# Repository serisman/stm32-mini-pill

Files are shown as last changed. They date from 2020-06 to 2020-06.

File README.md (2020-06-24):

# stm32-mini-pill
This is a development board for (LQFP-48) STM32 microcontrollers like the STM32F103C8T6 and STM32F072C8T6.
It is effectively 1/2 of the infamous 'blue-pill'.

Hold down the BOOT0/PA15 button while powering on (or press RESET and BOOT0 together, then release RESET) to access the built-in USB DFU bootloader.  The BOOT0/PA15 button can also be used for user input while not in the bootloader.

PCB design was done using KiCad.

PCBs are available at OSHPARK (or upload the included gerber.zip to your favorite board house):
https://oshpark.com/shared_projects/8USgL5pT

## 3D Renders:
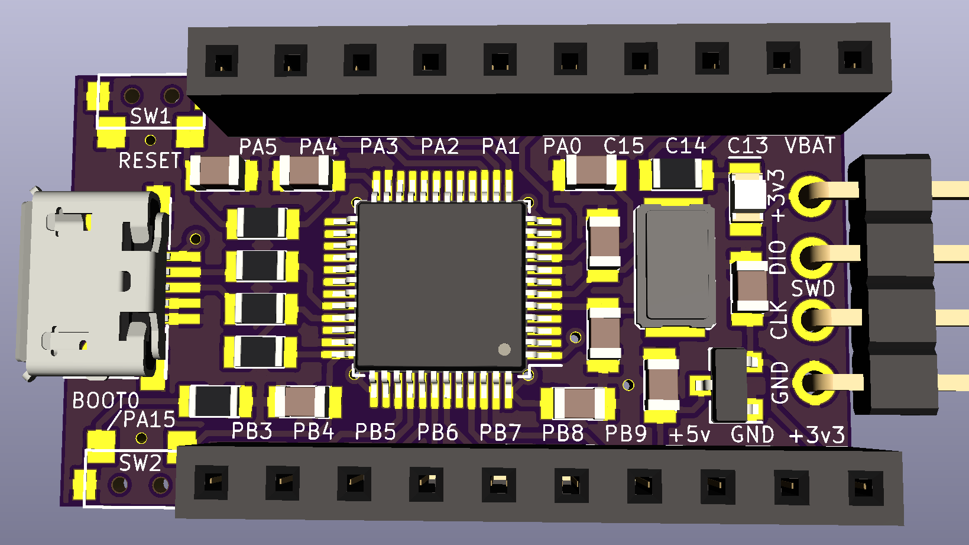
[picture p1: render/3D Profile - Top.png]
3D Profile - Top

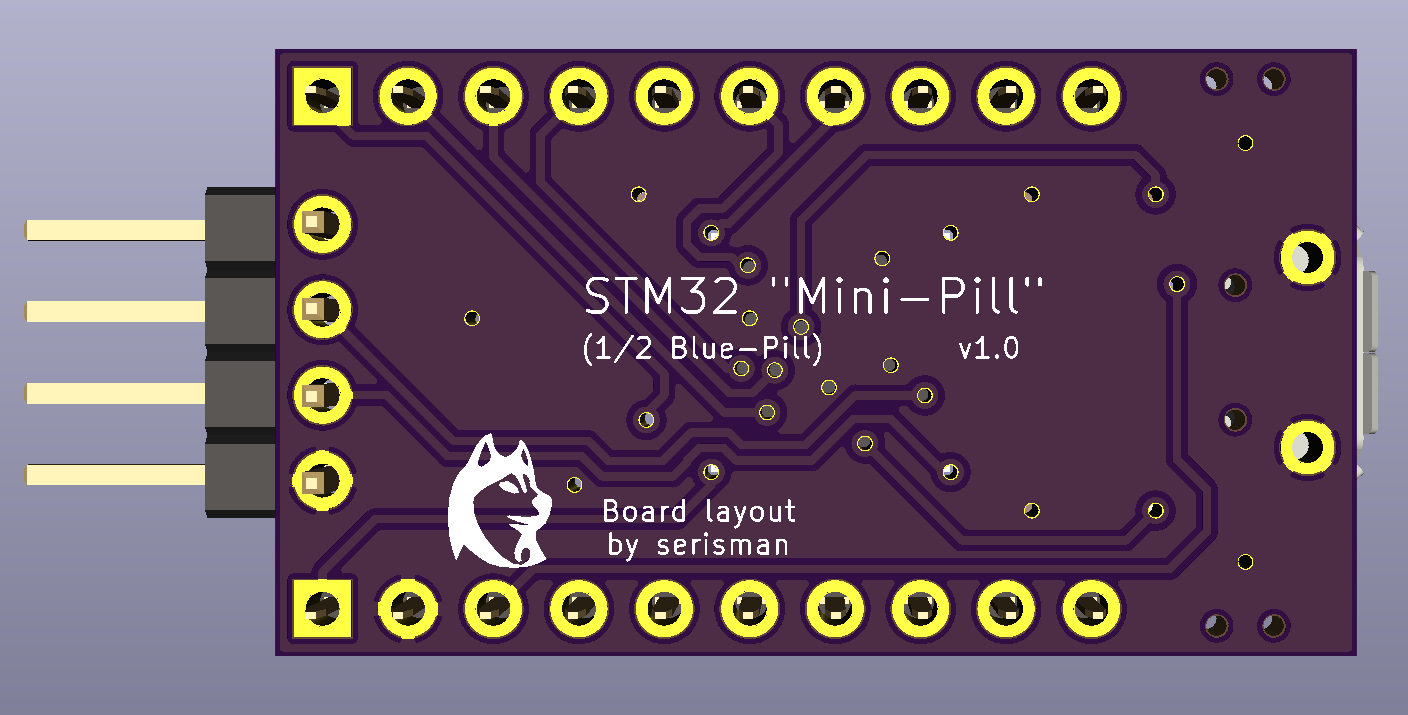
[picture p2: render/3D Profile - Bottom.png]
3D Profile - Bottom


## Finished Product:
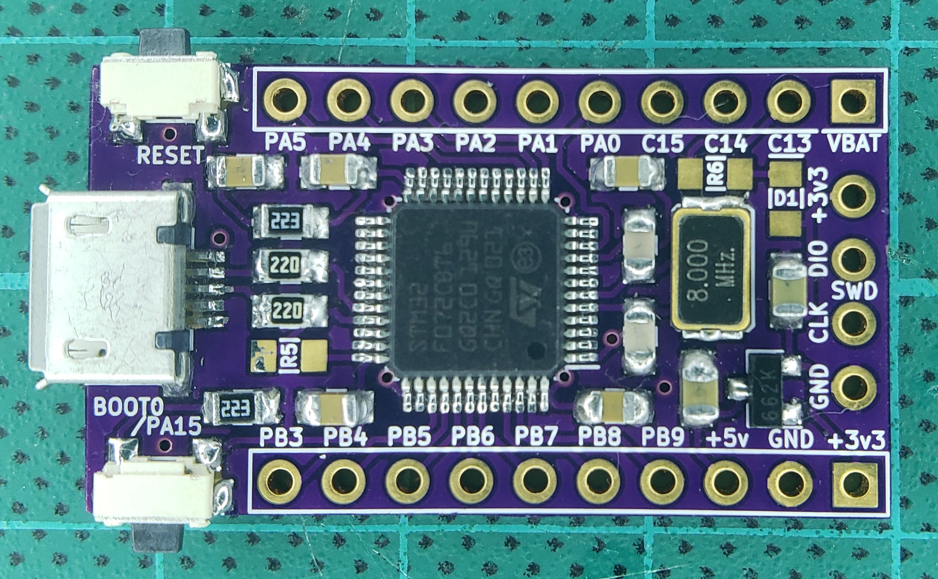
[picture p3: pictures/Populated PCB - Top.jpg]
Populated - Top

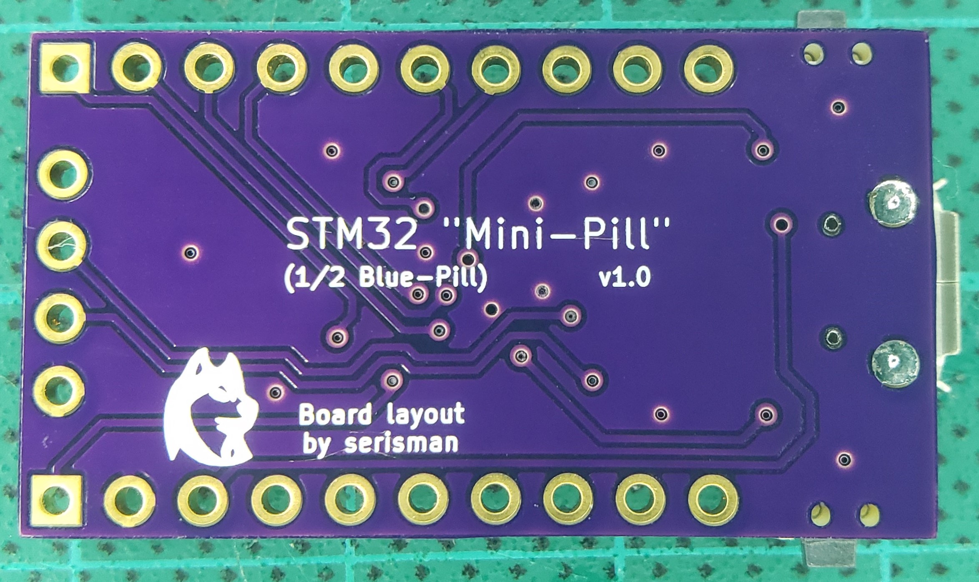
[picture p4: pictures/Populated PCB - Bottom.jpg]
Populated - Bottom


## Schematic:
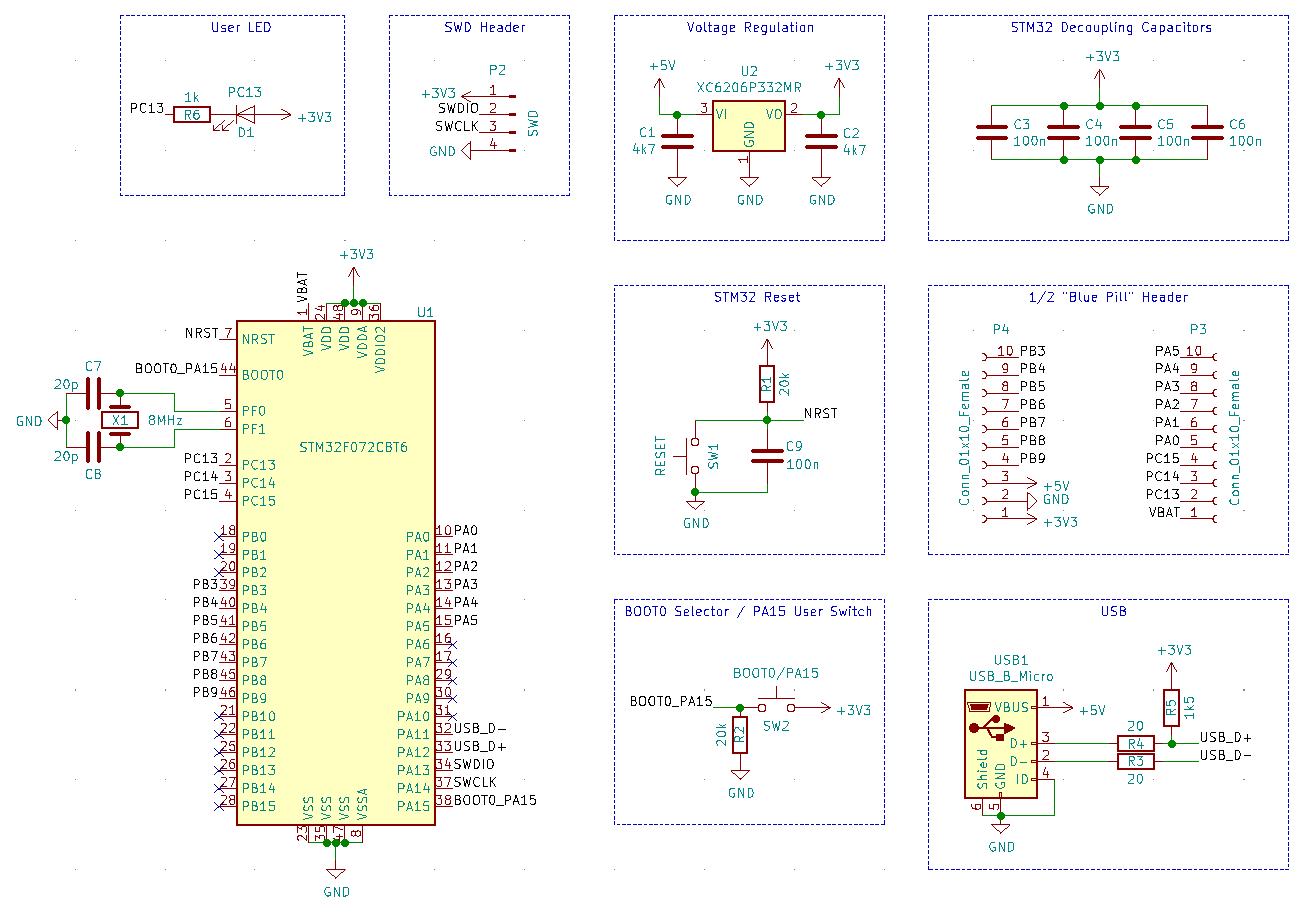
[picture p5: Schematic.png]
Schematic


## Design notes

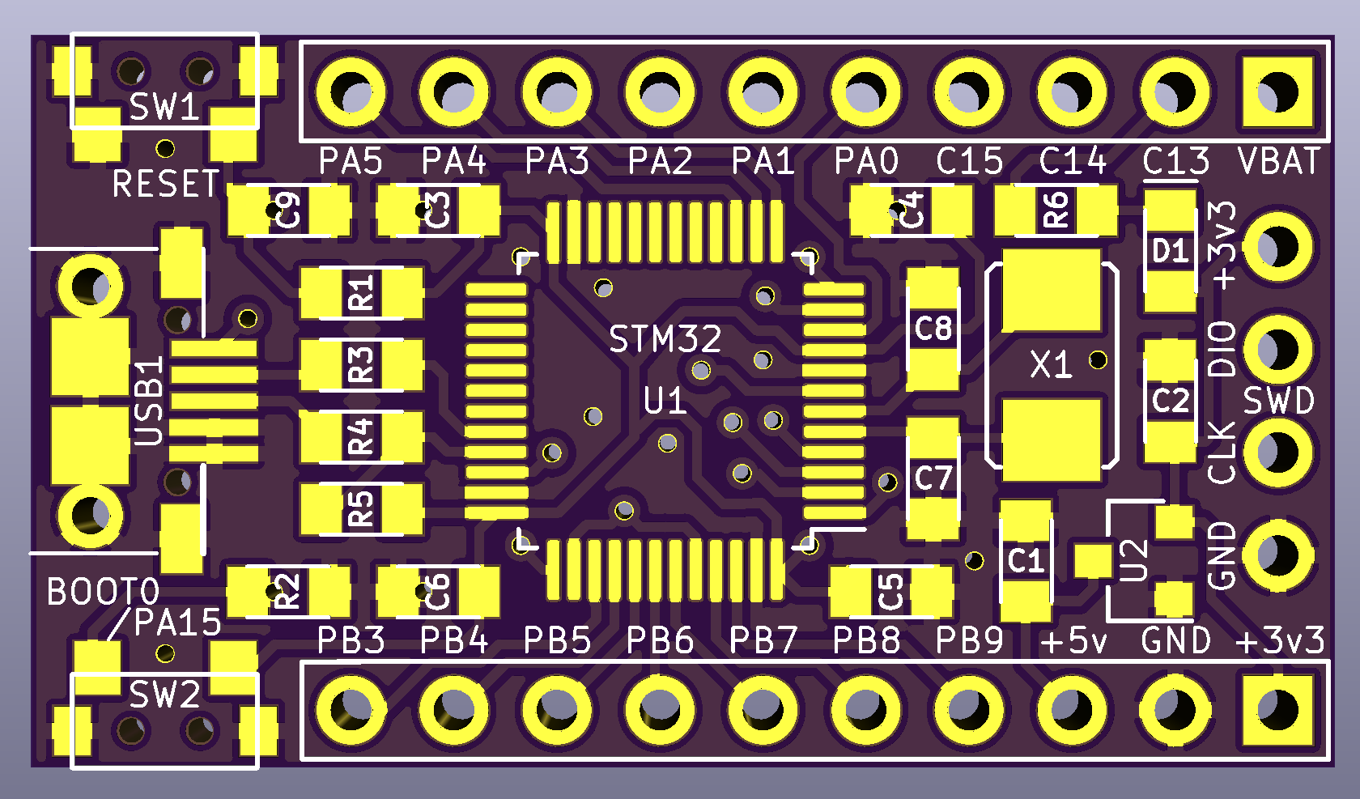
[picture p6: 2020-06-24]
render/PCB - Top.png

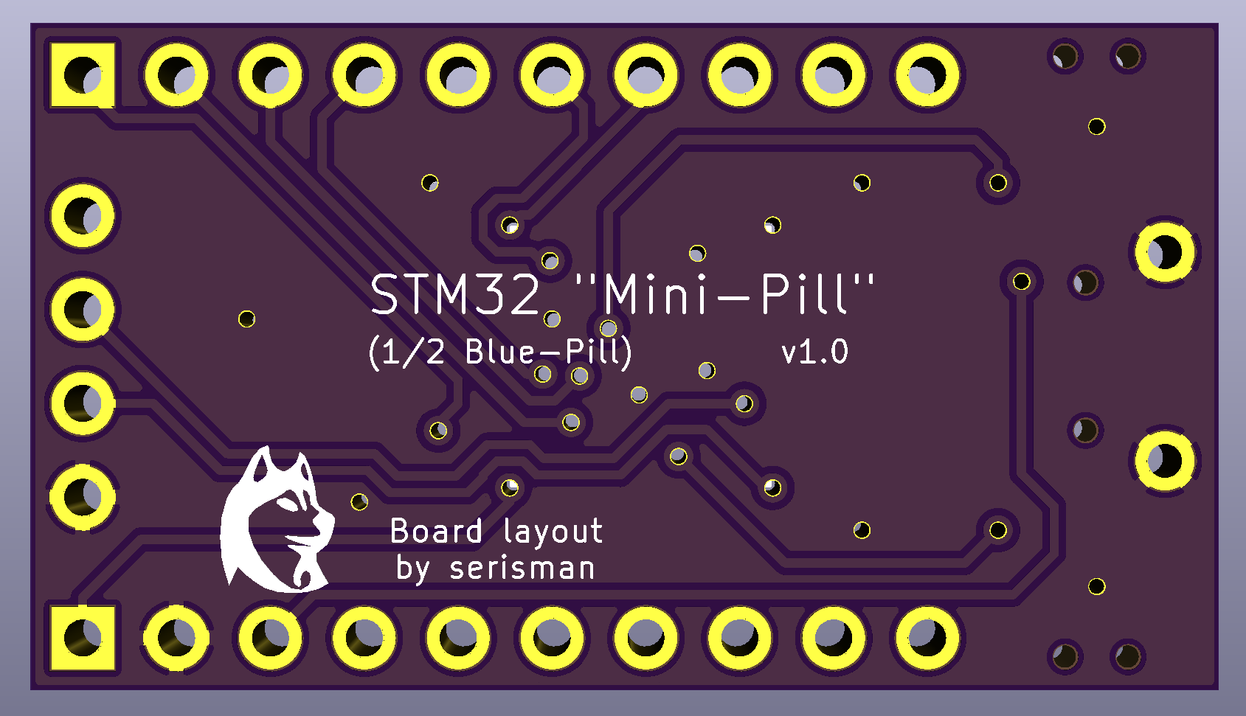
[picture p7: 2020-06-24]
render/PCB - Bottom.png

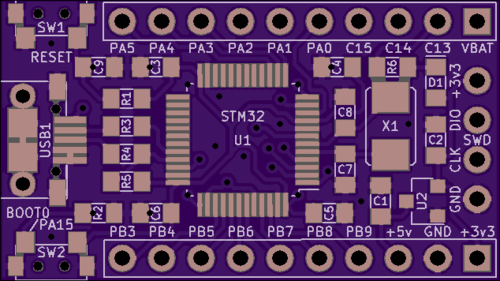
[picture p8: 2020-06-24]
render/OSHPARK - Top.png

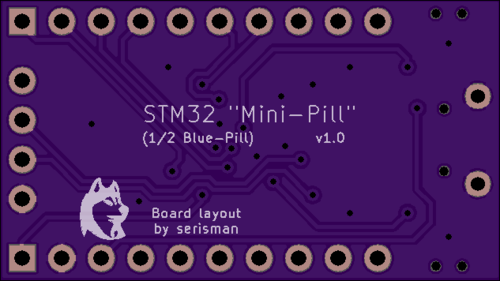
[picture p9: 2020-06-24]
render/OSHPARK - Bottom.png

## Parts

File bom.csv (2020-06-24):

References | Qty | Package | Description | MPN | LCSC | Comments
U1 | 1 | LQFP-48 |  | STM32F103C8T6 | C8734 | STM32 MCU - Can also be any other pin compatible (LQFP-48) STM32 MCU (i.e. STM32F072C8T6)
U2 | 1 | SOT-23 |  | XC6206P332MR | C347376 | 3.3v LDO regulator
X1 | 1 | 5032 2-pin |  | X50328MSB2GI | C115962 | 8MHz Crystal
USB1 | 1 | micro USB |  | MICRO5.9mmusb | C393940 | micro USB connector
SW1,SW2 | 2 | 3.5x4.55 mm |  | TS24CA | C393942 | RESET and BOOT0/PA15 buttons - side mount
C1,C2 | 2 | 0805 | 4.7uF 0805 Y5V | 0805F475Z100CT | C123638 | 3.3v LDO regulator in/out capacitors
C3,C4,C5,C6,C9 | 5 | 0805 | 100nF 0805 Y5V | 0805F104M500NT | C28378 | Bypass capacitors, Reset capacitor
C7,C8 | 2 | 0805 | 20pF 0805 C0G | 0805CG200J500NT | C94472 | Crystal load capacitors
R1,R2 | 2 | 0805 | 20k 0805 | 0805W8J0203T5E | C25624 | Button Pull-up/down resistors
R3,R4 | 2 | 0805 | 20 0805 | 0805W8J0200T5E | C25293 | USB resistors
R5 | 1 | 0805 | 1.5k 0805 | 0805W8J0152T5E | C26015 | USB pull-up (optional for some MCUs)
R6 | 1 | 0805 | 1k 0805 | 0805W8F1001T5E | C17513 | User LED current limit
D1 | 1 | 0805 |  | ORH-B35A | C205441 | User LED
P2 | 1 | 1x4 pin header |  | C91552 | C91552 | SWD header - right angle
P3,P4 | 2 | 1x10 pin header |  | C57369 | C57369 | User headers

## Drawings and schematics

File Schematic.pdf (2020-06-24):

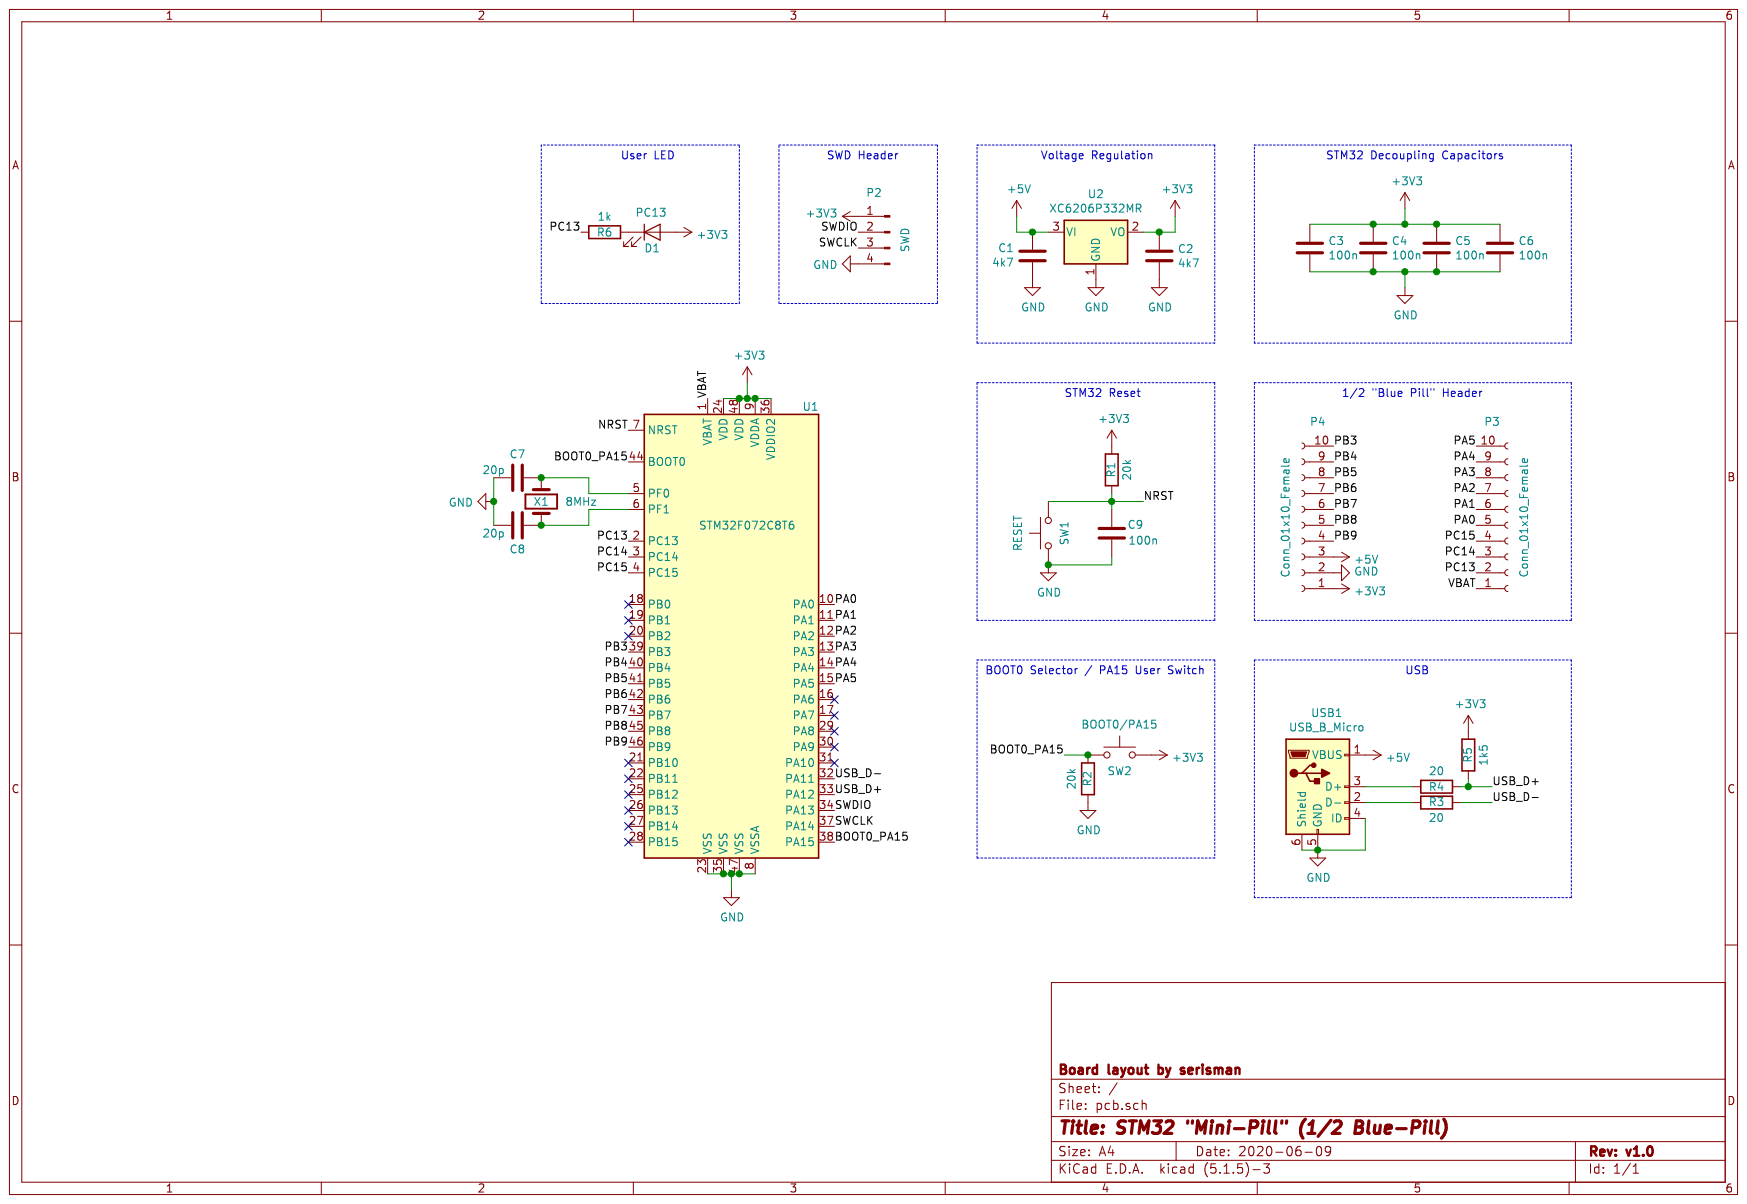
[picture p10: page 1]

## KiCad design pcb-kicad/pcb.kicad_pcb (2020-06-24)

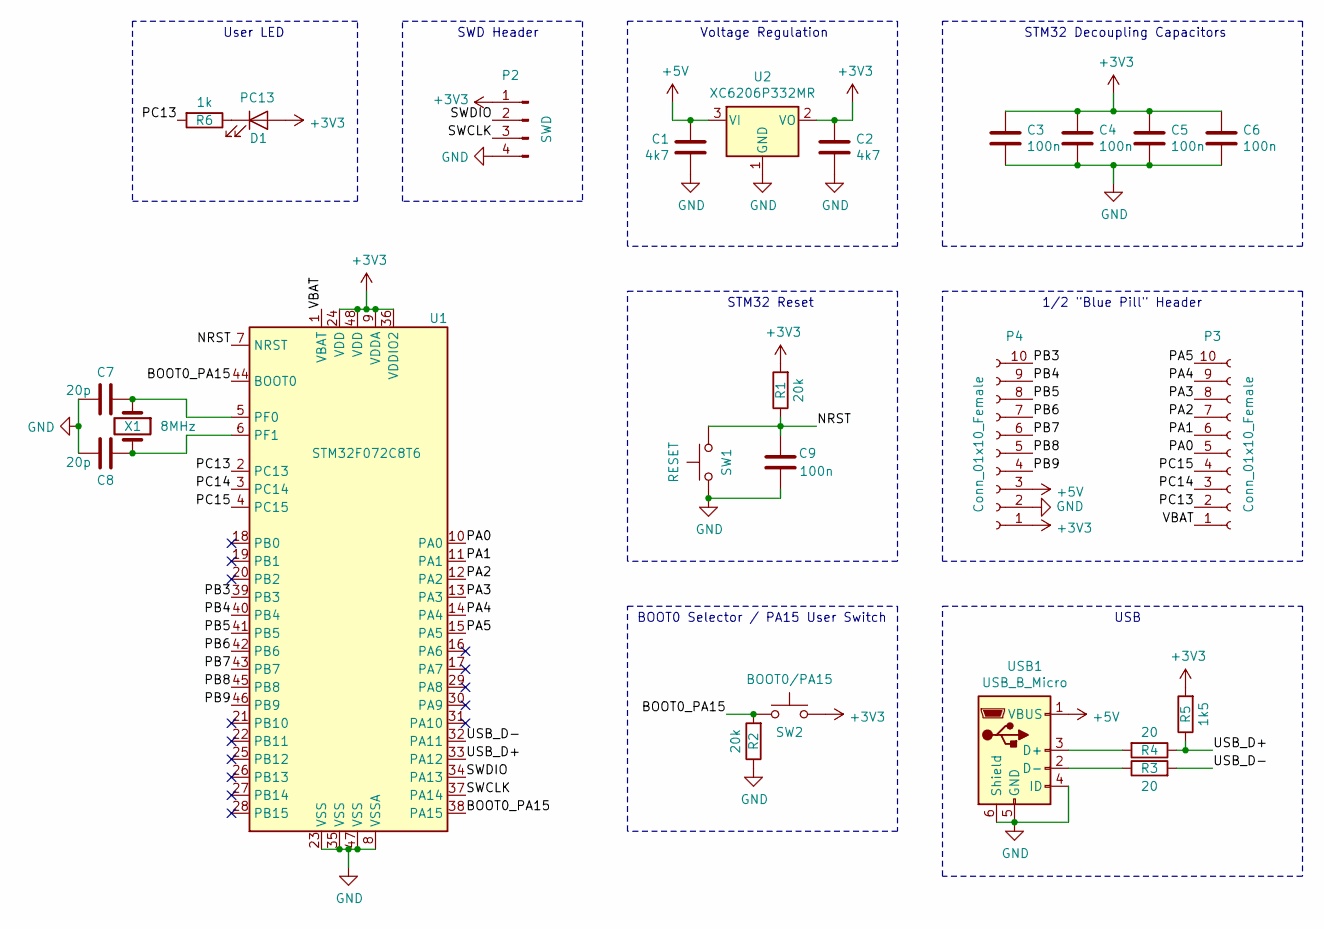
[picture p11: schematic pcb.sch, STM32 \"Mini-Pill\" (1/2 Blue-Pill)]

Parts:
C1, C2: 4k7; C_0805
C3, C4, C5, C6, C9: 100n; C_0805
C7, C8: 20p; C_0805
D1: PC13; LED_0805
P2: SWD; PinHeader_1x04_P2.54mm_Horizontal
P3, P4: Conn_01x10_Female; PinSocket_1x10_P2.54mm_Vertical
R1, R2: 20k; R_0805
R3, R4: 20; R_0805
R5: 1k5; R_0805
R6: 1k; R_0805
SW1: RESET; SMD-SW_Push_3.5x4.55_Side
SW2: BOOT0/PA15; SMD-SW_Push_3.5x4.55_Side
U1: STM32F072C8T6; LQFP-48_7x7mm_P0.5mm
U2: XC6206P332MR; SOT-23
USB1: USB_B_Micro; USB_Micro_B_Male
X1: 8MHz; Crystal_SMD_5032-2Pin_5.0x3.2mm

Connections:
+3V3: C2.1, C3.1, C4.1, C5.1, C6.1, D1.2 (A), P2.1, P4.1, R1.2, R5.2, SW2.1, U1.9 (VDDA), U1.24 (VDD), U1.36 (VDDIO2), U1.48 (VDD), U2.2 (VO)
+5V: C1.2, P4.3, U2.3 (VI), USB1.1 (VBUS)
/BOOT0_PA15: R2.2, SW2.2, U1.38 (PA15), U1.44 (BOOT0)
/NRST: C9.2, R1.1, SW1.2, U1.7 (NRST)
/PA0: P3.5, U1.10 (PA0)
/PA1: P3.6, U1.11 (PA1)
/PA2: P3.7, U1.12 (PA2)
/PA3: P3.8, U1.13 (PA3)
/PA4: P3.9, U1.14 (PA4)
/PA5: P3.10, U1.15 (PA5)
/PB3: P4.10, U1.39 (PB3)
/PB4: P4.9, U1.40 (PB4)
/PB5: P4.8, U1.41 (PB5)
/PB6: P4.7, U1.42 (PB6)
/PB7: P4.6, U1.43 (PB7)
/PB8: P4.5, U1.45 (PB8)
/PB9: P4.4, U1.46 (PB9)
/PC13: P3.2, R6.2, U1.2 (PC13)
/PC14: P3.3, U1.3 (PC14)
/PC15: P3.4, U1.4 (PC15)
/SWCLK: P2.3, U1.37 (PA14)
/SWDIO: P2.2, U1.34 (PA13)
/USB_D+: R4.1, R5.1, U1.33 (PA12)
/USB_D-: R3.2, U1.32 (PA11)
/VBAT: P3.1, U1.1 (VBAT)
GND: C1.1, C2.2, C3.2, C4.2, C5.2, C6.2, C7.2, C8.2, C9.1, P2.4, P4.2, R2.1, SW1.1, SW1.GND, SW2.GND, U1.8 (VSSA), U1.23 (VSS), U1.35 (VSS), U1.47 (VSS), U2.1 (GND), USB1.4 (ID), USB1.5 (GND), USB1.6 (Shield)
unnamed: C7.1, U1.5 (PF0), X1.1
unnamed: C8.1, U1.6 (PF1), X1.2
unnamed: D1.1 (K), R6.1
unnamed: R3.1, USB1.2 (D-)
unnamed: R4.2, USB1.3 (D+)

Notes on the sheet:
1/2 "Blue Pill" Header
Voltage Regulation
SWD Header
BOOT0 Selector / PA15 User Switch
STM32 Reset
USB
STM32 Decoupling Capacitors
User LED

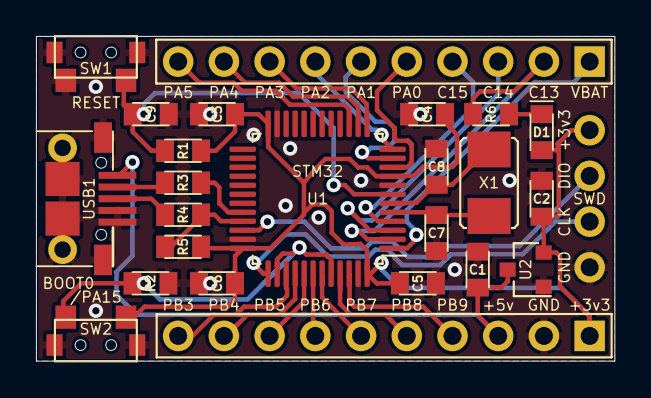
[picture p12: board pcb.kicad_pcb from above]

Board: 2 copper layers, 32.1 x 18.0 mm, 25 parts (0 on the bottom side), 31 nets.

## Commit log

2020-06-24 Initial Commit (v1.0)
    [pcb-B_Cu.gbr, pcb-B_Mask.gbr, pcb-B_Paste.gbr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]
2020-06-24 Add BOM
    [bom.csv]
2020-06-24 Optimize BOM
    [bom.csv]
